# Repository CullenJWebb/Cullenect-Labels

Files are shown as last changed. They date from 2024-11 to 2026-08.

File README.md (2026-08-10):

# Cullenect Labels
A standardized system of swappable 3D printed labels for Gridfinity and more. Thin and efficient labels with a satisfying *click* when inserted into a slot. 

## Related and Helpful Repositories
* [Cullenect Labels On Makerworld](https://makerworld.com/en/models/446624) - Pre sliced profiles for various hardware. Makeworld Customizer better supports color than vanilla OpenSCAD (for now).
* [gflabel by ndevenish](https://github.com/ndevenish/gflabel/) - A Python script to generate labels. Easy to automate and customize, supports many hardware and electronic icons.
* [Gridfinity Extended by ostat](https://github.com/ostat/gridfinity_extended_openscad) - A fork of Gridfinity with additional features and improvement. Generate bins with built in slots for Cullenect labels.
* [Cullenect Label Planner by dwfinkelstein](https://github.com/dwfinkelstein/cullenect-label-planner) - Keep a library of the labels you actually use, pick icons by looking at them, and export colored 3MF for one label or a whole packed build plate.

## Contributors
Thank you for the feedback and collaboration.

* [ndevenish](https://github.com/ndevenish/)
* [osts](https://github.com/ostat/)

## Standards and Dimensions - Gridfinity
Labels and sockets can be adapted to any size of bin. Custom label sizes are possible but these are the recommended dimensions:

### Label dimensions:
Labels feature a latch carved out of the entire perimeter of the label, allowing for socket ribs along either axis to hold the label in place.

* Label X (width): (42mm * Gridfinity_Units) - 6mm
  * Example: 1U = 36mm, 2U = 78mm, 3U = 120mm
* Label Y (height): 11mm
* Label Z (depth): 1.2mm
* Text Z (depth): 0.2mm (emboss or deboss)
* Label Latch XY inset: 0.2mm around the entire perimeter of the label
* Label Latch Z (depth): 0.6mm
* Label Latch Z Position: 0.2mm from the bottom of the label

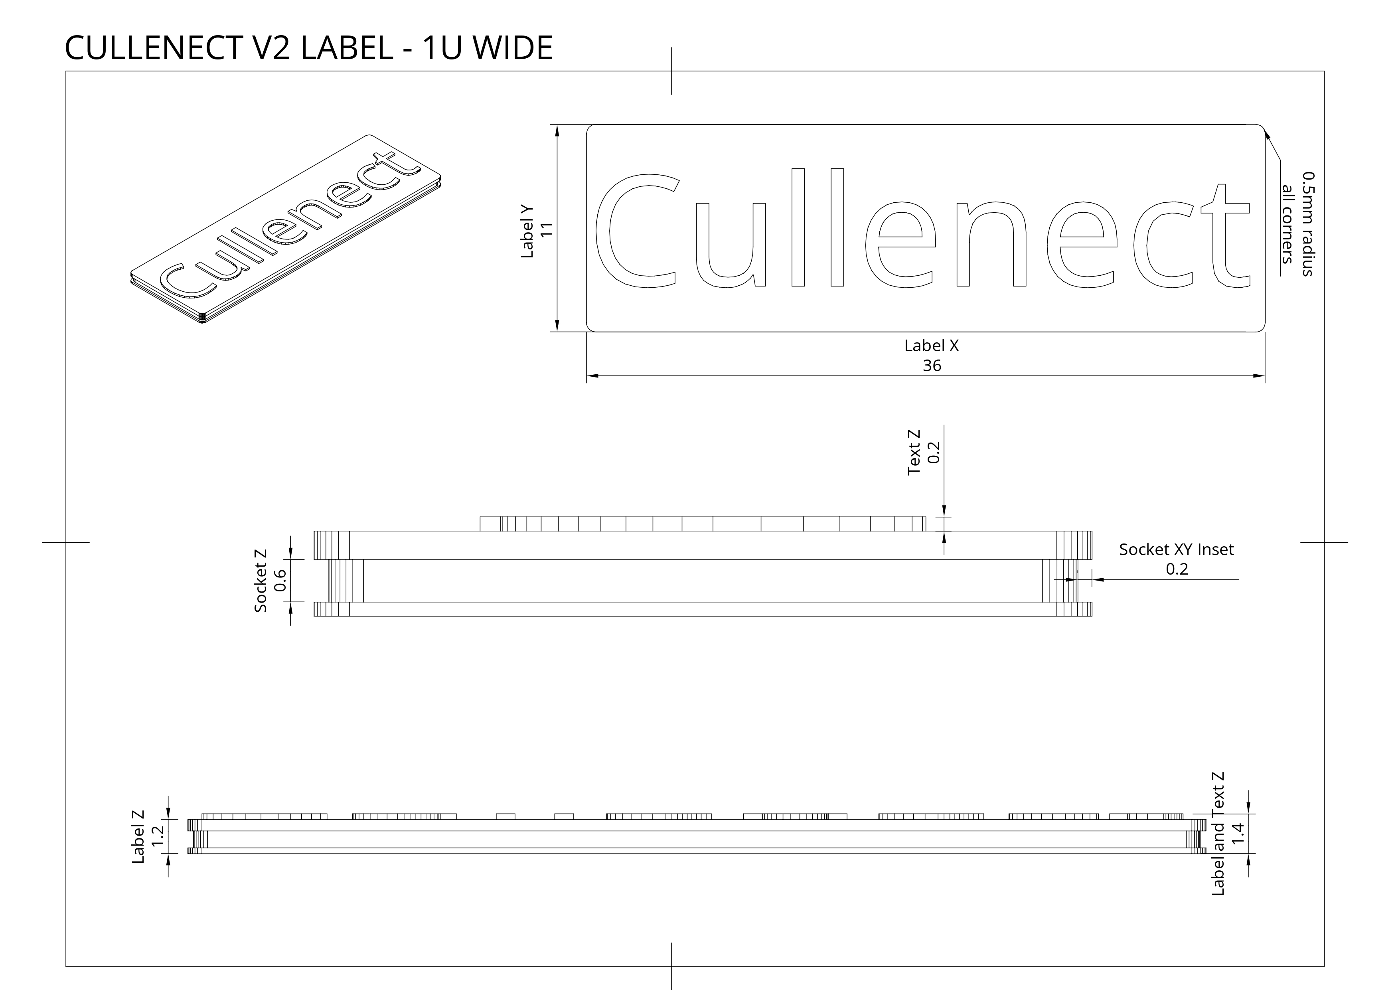
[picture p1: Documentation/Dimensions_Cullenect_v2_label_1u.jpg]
Dimensioned drawing of 1U labels


### Socket dimensions:
Sockets feature ribs along the X axis on boths sides of the socket to hold the label in place.

* Socket XY offset: 0.3mm
* Socket X: label_x + offset
  * Example: label_x = 36mm, socket_x = 36.3mm
* Socket Y: label_y + offset
  * Example: label_y = 11mm, socket_y = 11.3mm
* Socket Z (depth): 1.2mm
* Socket Rib XY: 0.2mm
* Socket Rib Z (depth): 0.4mm
* Socket Rib Z Position: 0.2mm from the bottom of the socket

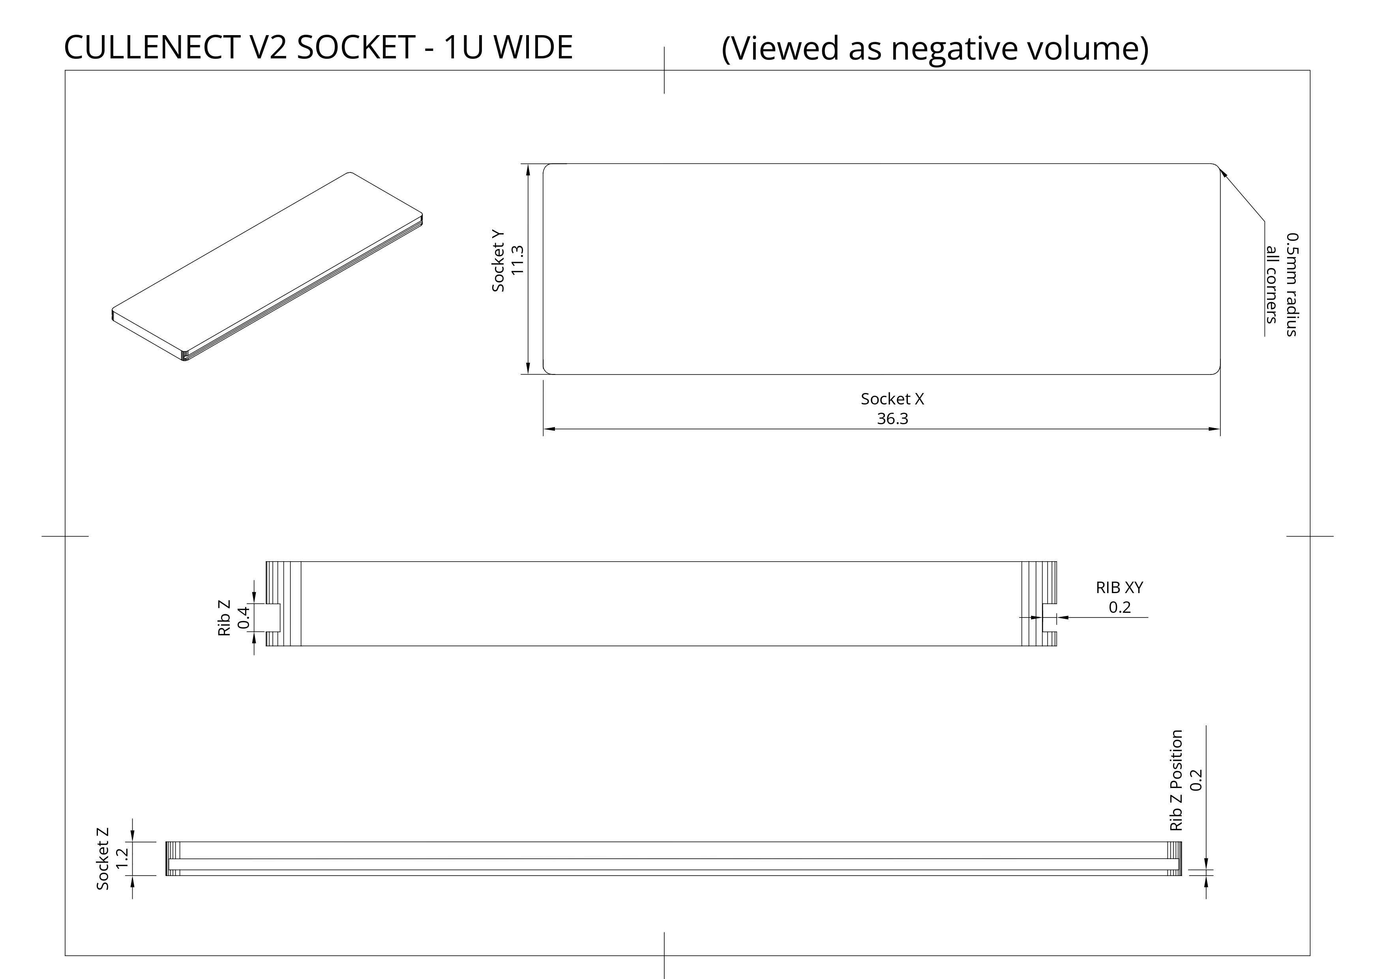
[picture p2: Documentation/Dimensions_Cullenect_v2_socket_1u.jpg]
Dimensioned drawing of 1U socket for labels


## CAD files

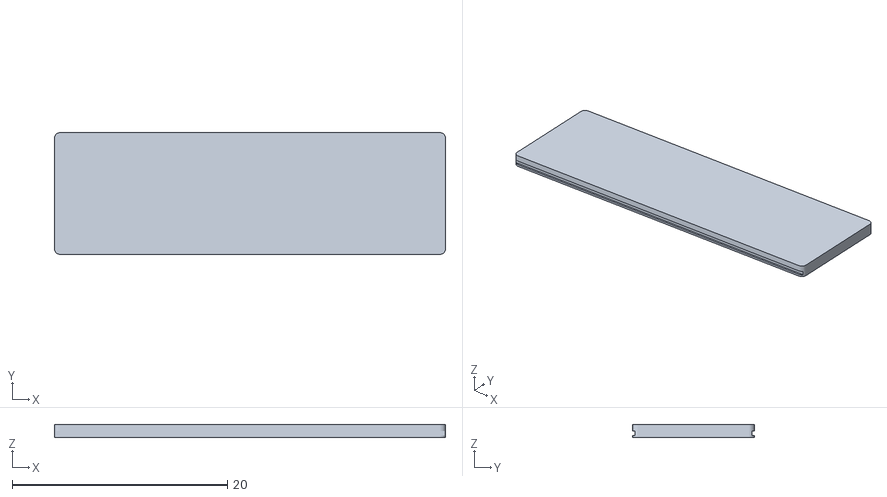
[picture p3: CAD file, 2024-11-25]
OpenSCAD/Cullenect Negative Volume.stl
36.3 x 11.3 x 1.20

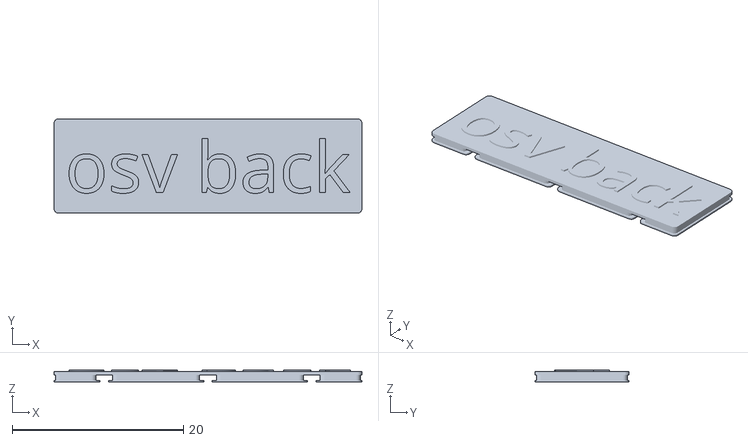
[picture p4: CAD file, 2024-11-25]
OpenSCAD/Cullenect.stl
36.0 x 11.0 x 1.40

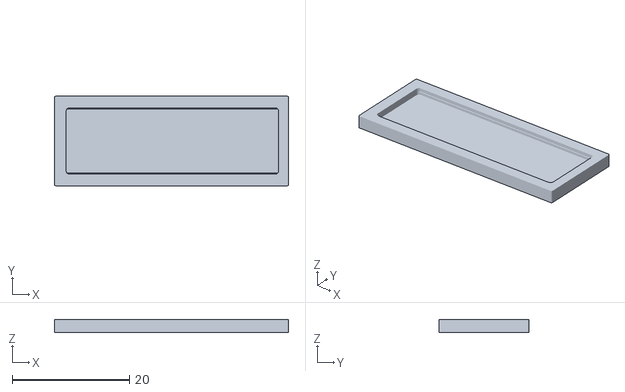
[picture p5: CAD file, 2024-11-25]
OpenSCAD/Cullenect Fitment Test.stl
40.0 x 15.3 x 2.20

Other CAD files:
OpenSCAD/Cullenect.scad

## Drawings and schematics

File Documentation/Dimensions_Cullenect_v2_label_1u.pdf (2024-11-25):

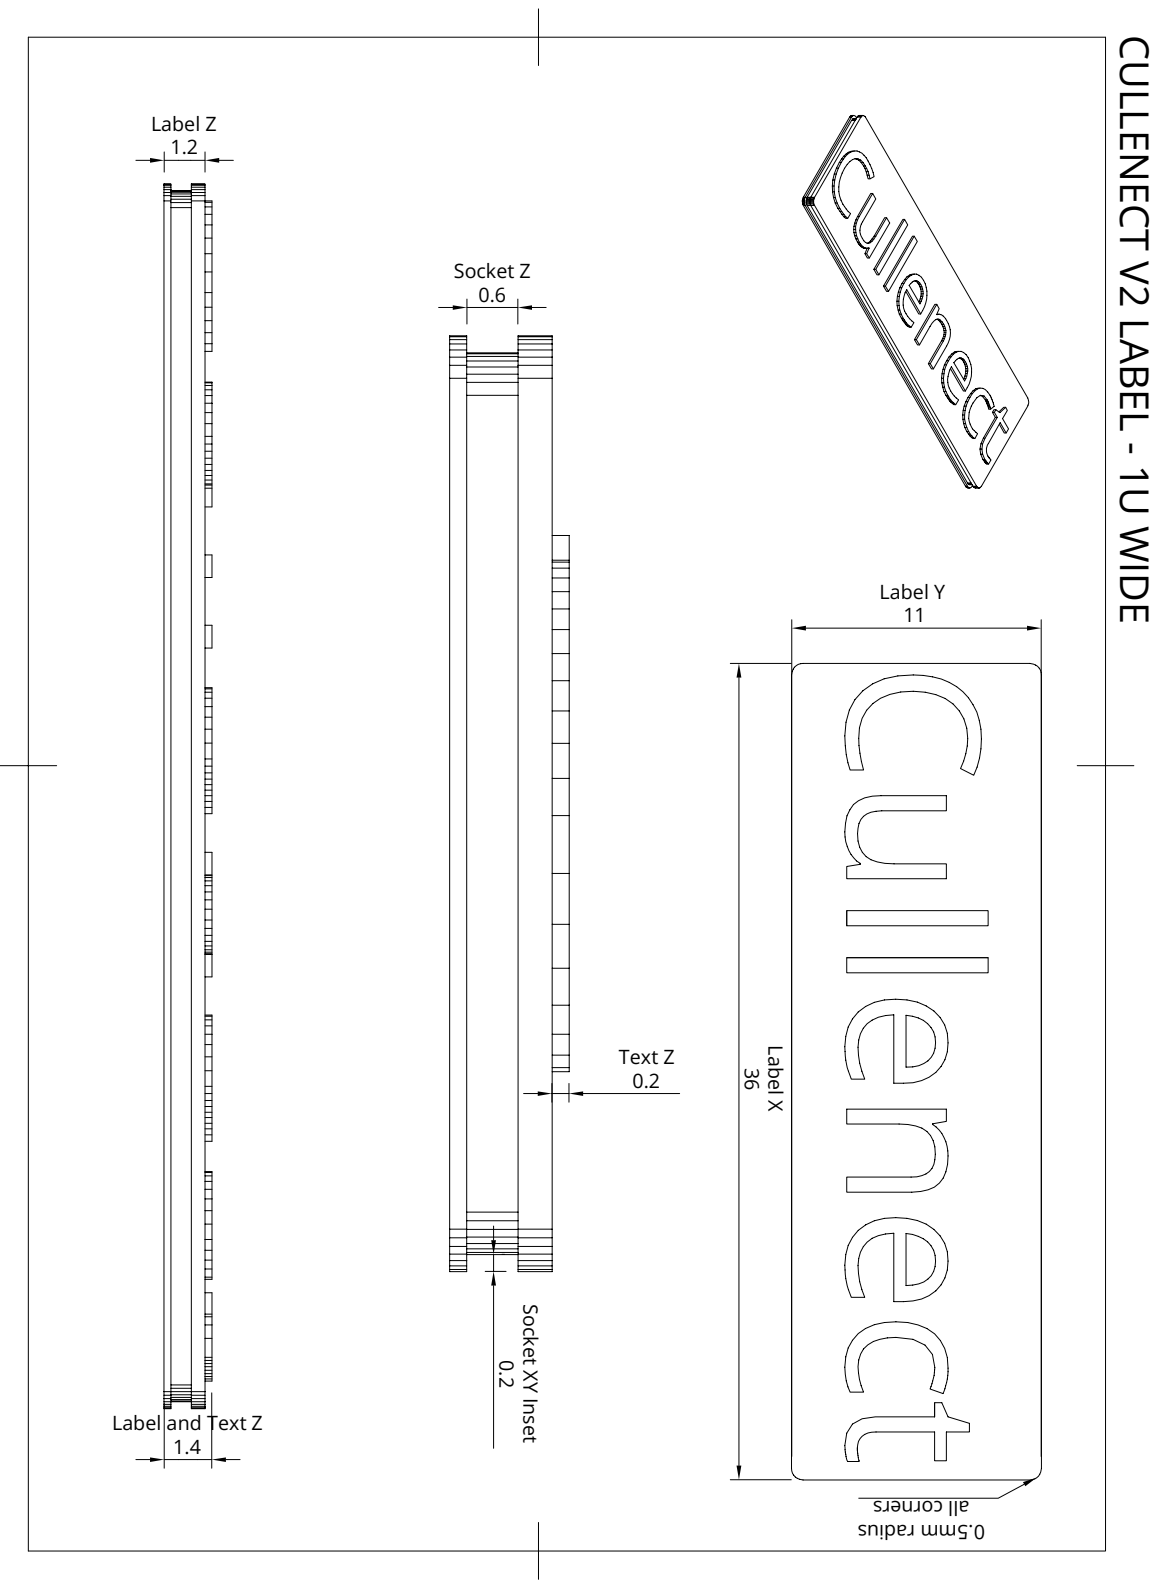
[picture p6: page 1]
Label X 36; Label Y; Socket Z 0.6; Label Z; Text Z 0.2

1.2 CULLENECT V2 LABEL - 1U WIDE

11 Socket XY Inset 0.2

Label and Text Z

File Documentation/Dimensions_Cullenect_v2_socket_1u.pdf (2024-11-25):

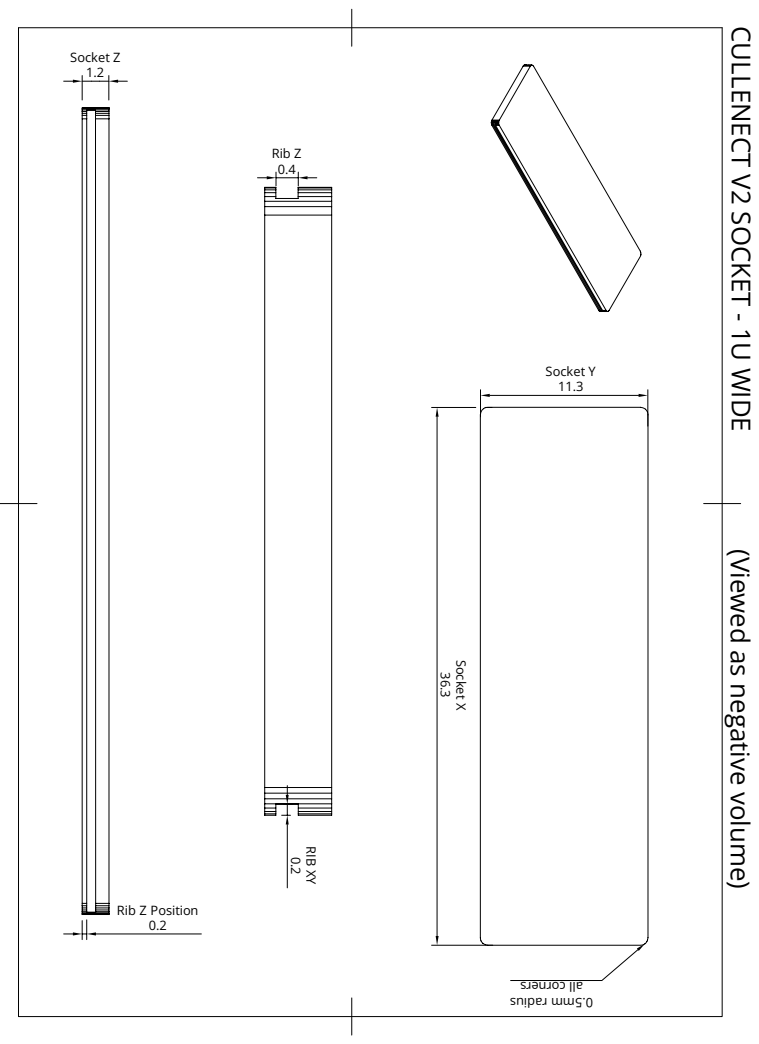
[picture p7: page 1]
Socket X 36.3; Socket Y 11.3 RIB XY 0.2; Rib Z 0.4; Rib Z Position 0.2

1.2 CULLENECT V2 SOCKET - 1U WIDE (Viewed as negative volume)
Socket Z

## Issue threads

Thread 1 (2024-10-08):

Doesn't appear to generate any text

lsd87, 2024-10-08:
Can't see any text generation on the label, even after F6
SCAD V2024.09.30

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

CullenJWebb, 2024-10-21:
Sorry about that, I mixed up the branches. You can download it again and you should have a working version.

lsd87, 2024-10-21:
Thanks - lot better
Changing the font family does not appear to do anything is this due to running on windows 10 ?

Looking forward to chris (osat) installing the vertical click rails in his bin generator

Thanks

CullenJWebb, 2024-10-22:
@lsd87 That may be because you don't have the fonts installed.

I've added it to the makerworld listing here if you want to try out the fonts there without installing: https://makerworld.com/models/446624

I'm very excited to see Chris integrate the socket in his bins. I may make my own solution in the meantime to replace the V1 bins on makerworld ASAP.

lsd87, 2024-10-22:
Installed fonts and now works fine.

Do you know is gflabel @ndevenish will support your click V2 ?

CullenJWebb, 2024-10-23:
@lsd87 I believe so, I've kept them up to date with the progress on V2 and they expressed interest in keeping gflabel up to date.

ndevenish, 2024-10-23:
I plan to, but was only told about the v2 release two days ago! I plan to have a look this weekend to see how close to the prototype v2 the final release is, and update.

CullenJWebb, 2024-10-23:
@ndevenish Thank you thank you!

Closed 2024-10-22.

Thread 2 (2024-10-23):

add specification to read me

ostat, 2024-10-23:
To make implementation of the labels and receiving holes easier, could you please add some details about the read me about the specifications.
What dimensions should the label be including each of the heights for the click mechanism.
What dimensions should the receiving hole be, including the click mechanism, and the amount of expected clearance.

If we are not yet sure of the dimensions this can serve as a starting point to work from to ensure consistency across implementations.

CullenJWebb, 2024-10-23:
Good thinking, I'll get on that.

ostat, 2024-10-26:
With regards to the specifications. I notice that the two click ribs on V2 are at different heights. Which side should go to the front/bottom?

This does mean that a label printed to go on the back of a bin, wont work on the front (as the same side will always be on the inside). The generator might need support for rotating the text.

CullenJWebb, 2024-10-30:
While I have your ear, do you have a preferred way to create dimensioned drawings from STL files?

I am creating the specifications for the readme but I haven't found a good way to create the drawings.

ostat, 2024-10-30:
you can add dimensions to a openscad drawing. But its a pain and manual.
I do it in Gridfinity extended, That that is mostly so people know what size they are generating.

I would prob use a third party tool, like onshape. In there you can create a sketch that will look nice and have all the detail.

CullenJWebb, 2024-11-25:
@ostat All set on those specifications, I've updated the readme. Please take a look and let me know if there are any details missing.

Thanks!

darsor, 2025-01-18:
The drawings in the README were very useful. I also noticed the height difference in the sockets (which doesn't match the drawings), which is still present on main.

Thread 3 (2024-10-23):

design feedback

ostat, 2024-10-23:
@CullenJWebb, great work on the new design of the labels.

If you don't mind, could we provide feedback on the design?

If we can it would be nice to not need to use supports when printing. I assume most people will print this text side up. Is there an opportunity to add a chamfer to the underside of the upper lip?
In version 1 this did not add much value as the ribs in the middle were still not supported, in version 2 I think this adds value.

This is just a draft, to explain what I mean.
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

Aesthetically, I would make the radius if the inner setback different from the outer, so that there is a consistent overhang.
Currently
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
Suggested
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

I can submit PR's if you are interested

CullenJWebb, 2024-10-23:
I will check on the radius.

The chamfer from V1 isn't needed though, I think. The overhang is so small that it holds form really well and keeps the geometry simpler.

Same for the socket rails, they don't have chamfers but their width was less than the nozzle extrusion width on a 0.4mm.

What printers do you have? I don't have any old ones around to test with and I do want to make sure that enders and other bedslingers can print them so I'll test the chamfer just in case we need them.

ostat, 2024-10-24:
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

oh right, I didn't really consider the scale of the model when looking at it

CullenJWebb, 2024-10-24:
> oh right, I didn't really consider the scale of the model when looking at it

This tripped me up so much during the design of both V1 and V2. Being able to zoom in and rotate around causes me to lose all sense of relative size.

This was why V1 had such bad vertical sockets, I didn't appreciate the fact that printers wouldn't be able to print the 3 latches when they were turned on their side. V2 still requires some creative movements to be modeled into the 2 side rails so that it can be printed in a single motion without any seams.

Closed 2024-10-24.

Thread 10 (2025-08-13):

Request:  Additional icons

braunm, 2025-08-13:
Loving the system so far; I'm about halfway done with my hardware stash. I saw on the Makerworld site that you had some additional icons in the works.  If you are still amenable, here are the ones I could use.

Already on your MW list:

- wing nuts
- carriage bolts
- dowel pins
- bearings

And some new ones:
- hex bolts / cap screws / lag bolts
- Wago-style lever nuts (for electrical)
- set screws
- head for T-bolt (like [these](https://powertecproducts.com/qtb1008-tee-bolt-1-4-20-1-1-2-long-20-pk/))
- Euro-screws (like [these](https://www.rockler.com/centerline-5mm-x-10mm-flat-head-pozi-drive-euro-screws-nickel-100-pack))
- Pozi-drive drive type
- drywall anchors / toggle bolts / etc.
- pins / brads / crown staples / etc
- springs (compression and extension)
- metal rods (threaded and not)

I tried creating some of these myself in Fusion.  They were not good.  Graphic design is not my strength.

Anyway, thanks for all you've done on this project so far.  It's a winner.

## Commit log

2024-09-14 Beta
    Created labels and socket in openscad. Socket needs improvement and v-socket is not ported.
    [Cullenect.scad]
2024-09-14 Added model selector.
    Socket still needs adjustment.
    [Cullenect.scad]
2024-09-15 Finalized socket
    h socket finalized, started on v socket.
    [Cullenect.scad]
2024-09-21 Started vertical slot upper chamfer, needs rotation and sizing
    [Cullenect.scad]
2024-10-21 Vertical Socket Negative Complete
    Still need to do Vertical Socket
    [Cullenect.scad]
2024-10-24 Update Cullenect.scad
    Fixed a quick error on the socket rails/ribs. I accidentally left one at a test height of 0.4
    [Cullenect.scad]
2024-11-25 Updated readme
    Added dimensioned drawings and outlined standard in readme.
    [Cullenect Fitment Test.stl, Cullenect Negative Volume.stl, Cullenect.scad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]
2025-04-30 v2.0.2
    New hardware, fasteners, and features. Description on MakerWorld.
    [Cullenect.scad]
2026-06-02 Add crimp butt splice hardware icon
    [Cullenect.scad]
